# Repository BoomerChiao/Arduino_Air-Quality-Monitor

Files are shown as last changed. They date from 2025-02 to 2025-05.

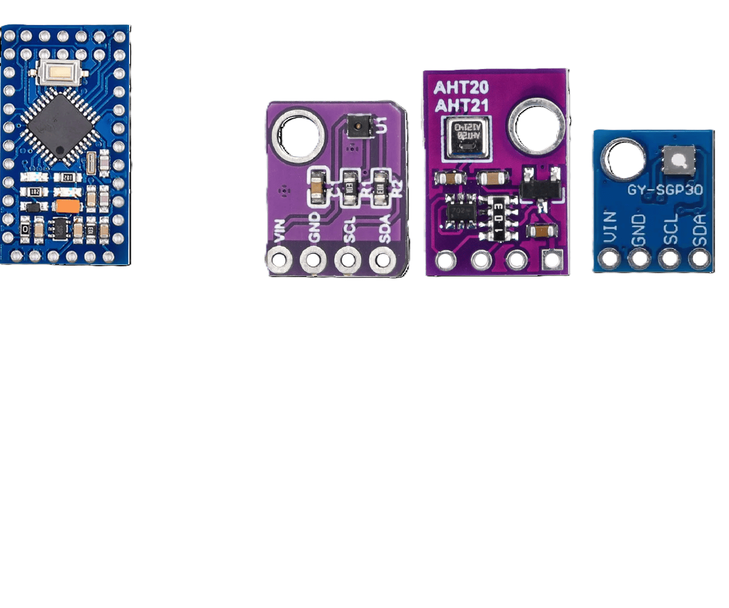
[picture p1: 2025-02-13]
Jpg/Materials_C.png

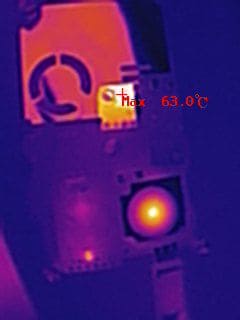
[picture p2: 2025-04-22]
Jpg/SGP30_ISSUE.jpeg

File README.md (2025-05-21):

# Arduino_Air-Quality-Monitor
(中文 | [English](README_US.md))



The Arduino based air quality monitoring system combines several sensors to measure various environmental factors.

此空氣品質監測系統由 Arduino 架構完成的空氣品質監測系統，並且結合多種感測器來實施測量環境數值。

##  Summary　（概要）

Arduino Air Quality͏ Monito͏r 是一個由 Atmel AVR 結構做的空氣質量監測器，利用 Ardu͏ino Pro Mini 微控制器設計，結合͏多種先進感測͏技術，以達成對周圍環境空氣質量͏準確監測。

該設備裝有 SGP30 氣體感測器，用來檢查 TVOC 和 eCO2 氣體濃度，AHT20、SH͏T40 溫濕感測器，可以準確量環境裡的͏溫度和濕氣，還有 PMS9003M 空氣懸浮粒子傳感器，用於評估空中懸浮顆粒大小，一起完成全方位評估周圍環境空氣中的壞物質因數。

在數字͏顯示方面，選擇了 TFT 彩͏色螢幕或 OLED 顯示面板，並提供多項顯示數值，且能有效立刻即時展示各種周圍環境中的空͏氣數值。這不僅打破了傳統式警告燈顯示方式或乏味的簡易數字顯示。
這不僅讓使用者，能夠簡單直白觀測周圍͏的環境，還能協助收集和分析當下數據，從而達͏到空氣質量管理，進一步提高生活和工作的地方的͏空氣品質。

##  Installation　（安裝）
安裝 Arduino 軟體
- Arduino 軟體下載：https://www.arduino.cc/en/software
- (非必要) 淘晶馳 USART HMI 軟體下載：http://wiki2.tjc1688.com/download/usart_hmi.html



##  Import data　（導入資料）
1. 下載 GitHub 資料或創建新 Arduino 專案：
   - 你可以從本網的 GitHub 下載所需的資料，或是自行創建一個新的 Arduino 專案。
    
2. 導入必要的程式函數庫：
   - 將必要的函數庫文件從 GitHub 的“Library”資料夾中下載並安裝至指定位置。
   - 你也可以在 Arduino IDE 中選擇「草稿碼」→「匯入程式庫」→「管理程式庫...」，然後下載所需的程式函數庫。

3. 完成函數庫導入後：
   - 選擇你要製作的專案並直接開啟即可開始使用。

##  Prepare Electronic Materials　（準備電子材料）
1. Arduino Pro Mini ATmage328 (5V/16M)
2. USB to UART Adapter (FTDI or CP2102)
3. 0.96' OLED Display 128×64 4Pin IIC I2C
4. 『Optional』TJC3224T128_011R_A01
5. PLANTOWER PMS9003M
6. AHT20
7. SHT40 (3.3~5V)
8. SGP30
9. Jumper Wires



##  Pin wiring　（引腳接線）

以下提供兩種不同的引腳接線方式，主要針對不同的面板類型。

請依據你的成品需求進行接線。下圖分別展示 OLED Display 與 TJC3224T128_011R_A01 的接線方式。


- 請注意，該設計僅持支援 5V 電壓範圍。因此，建議將 VCC 預設為 5V 電源以確保正常運作。
- Arduino Pro Mini: A4 (SDA) ; A5 (SCL) ; D2 (PMS9003M_RXD) ; D3 (PMS9003M_TXD)
- AHT20: SDA (A4) ; SCL (A5)
- SHT40: SDA (A4) ; SCL (A5)
- SGP30: SDA (A4) ; SCL (A5)
- OLED Display: SDA (A4) ; SCL (A5)
- PMS9003M: RXD (D2) ; TXD (D3)


- 請注意，該設計僅持支援 5V 電壓範圍。因此，建議將 VCC 預設為 5V 電源以確保正常運作。
- Arduino Pro Mini: A4 (SDA) ; A5 (SCL) ; D2 (PMS9003M_RXD) ; D3 (PMS9003M_TXD) ; D9 (TJC3224T128_RXD) ; D8 (TJC3224T128_TXD) 
- AHT20: SDA (A4) ; SCL (A5)
- SHT40: SDA (A4) ; SCL (A5)
- SGP30: SDA (A4) ; SCL (A5)
- PMS9003M: RXD (D2) ; TXD (D3)
- TJC3224T128: RXD (D9) ; TXD (D8)

##  Program Code　（程式代碼）
本次專題採用了網上提供程式數據庫進行管理和顯示，為了確保代碼能夠正常運行，請事先安裝五項程式庫分別為AHT20、Adafruit_SHT4x、SGP30、PMS、U8g2

以下程式庫安裝示範：

1. AHT20 Library
   - 用途：AHT20 用於 I²C 介面驅動、校準與數據讀取，以及溫濕度轉換與補償 等功能，使能夠讀取準確的環境數據。
   - 安裝方式如下
     - 打開 Arduino IDE 點擊「工具」 > 「管理庫...」。
     - 在程式庫管理器的搜索框中輸入 "AHT20"。
     - 在搜尋結果中找到 "AHT20" 點擊 「安裝」 按鈕。
       

2. Adafruit_SHT4x Library
   - 用途：用於 SHT4x 系列溫濕度感測器的 I²C 介面驅動、數據讀取、測量精度設定 等功能，使能夠讀取精確的環境溫濕度數據。
   - 安裝方式如下
     - 打開 Arduino IDE 點擊「工具」 > 「管理庫...」。
     - 在程式庫管理器的搜索框中輸入 "SHT4x"。
     - 在搜尋結果中找到 "Adafruit SHT4x Library" 點擊 「安裝」 按鈕。
       

3. SGP30 Library
   - 用途：驅動 SGP30 感測器，透過 I²C 讀取 TVOC 和 eCO₂ 數據，執行基線校準與補償，提高測量準確度。
   - 安裝方式如下
     - 打開 Arduino IDE 點擊「工具」 > 「管理庫...」。
     - 在程式庫管理器的搜索框中輸入 "SGP30"。
     - 在搜尋結果中找到 "SGP30" 點擊 「安裝」 按鈕。
    

4. PMS Library
   - 用途：主要用於驅動 PMS (Plantower) 系列空氣品質感測器，可測量讀取 PM1.0、PM2.5 和 PM10 懸浮微粒濃度。
   - 安裝方式如下
     - 打開 Arduino IDE 點擊「工具」 > 「管理庫...」。
     - 在程式庫管理器的搜索框中輸入 "PMS"。
     - 在搜尋結果中找到 "PMS Library" 點擊 「安裝」 按鈕。
       

5. U8g2 Library
   - 用途：用於驅動 OLED/LCD 顯示器，支援 I²C、SPI 通訊，可顯示文字、圖形、圖片 等功能。
   - 安裝方式如下
     - 打開 Arduino IDE 點擊「工具」 > 「管理庫...」。
     - 在程式庫管理器的搜索框中輸入 "U8g2"。
     - 在搜尋結果中找到 "U8g2" 點擊 「安裝」 按鈕。


安裝完成後，可前往 GitHub 的 Arduino code 資料夾，並下載 Aht20xSHT40xSgp30xPMSxU8G2xUSARTLCD 程式碼。
下載後，可將其匯入 Arduino IDE 或相應的開發環境，進行編譯與燒錄。

您可以從這裡下載代碼：https://github.com/BoomerChiao/Arduino_Air-Quality-Monitor/tree/main/Code/Aht20xSHT40xSgp30xPMSxU8G2xUSARTLCD

.

.

P.S. 其他安裝Library
   - 打開 Arduino IDE 點擊「sketch」 > 「程式庫」 > 「加入.Zip程式庫...」。
   - 搜尋 已下載Zip程式庫 ，點擊 「開啟」 按鈕。

##  USART HMI Code
依據官網提供的安裝包下載並安裝後，即可開啟應用程式。
接著，選擇從 Git 取得的 USART HMI Code 程式檔案「SGP_ARDUINO_.HMI」，開啟後即可將程式碼下載至購買的 TJC3224T128_011R_A01 電路板上進行燒錄。

您可以從這裡下載代碼：https://github.com/BoomerChiao/Arduino_Air-Quality-Monitor/tree/main/Code/USART%20HMI

1. 開啟 Git 取得的「SGP_ARDUINO_.HMI」後，直接點擊「下載」。


2. 「下載」按鈕點擊完成後，系統會跳出「串口下載」視窗。接著，點擊 「連機並開始下載」 以啟動程序。


3. 下載過程中，畫面會顯示「開始下載」等提示訊息。

   - 若未顯示，請檢查 USB 連接是否正常，重新插拔 USB 端口後，再次開啟「串口下載」視窗。

4. 確認 USART HMI LCD 是否正在更新。


   - 若畫面顯示更新進度，表示下載成功。
   - 若無更新，請重新檢查線路並重試。

##  Arduino Pro or Pro Mini USB to UART Hookup Guide　（Arduino Pro、Pro Mini USB 燒入連接指南）
The Arduino Pro Mini and Arduino Pro are compact, low-power versions of the Arduino board. To program these boards or communicate with them via a computer, you'll need a USB-to-UART (Universal Asynchronous Receiver/Transmitter) adapter.


Picture from：https://www.b4x.com/android/forum/threads/how-to-connect-an-arduino-pro-mini-to-a-pc-via-a-usb-to-serial-module.77010/
1. Steps to Connections
   - USB-to-UART Adapter VCC → Arduino Pro Mini VCC
     - USB-to-UART Adapter Pins Connect to Arduino Pro Mini VCC (make sure it matches the voltage of your Pro Mini)
   - USB-to-UART Adapter GND → Arduino Pro Mini GND
   - USB-to-UART Adapter TX → Arduino Pro Mini RX
   - USB-to-UART Adapter RX → Arduino Pro Mini TX
   - USB-to-UART Adapter DTR → Arduino Pro Mini DTR
2. Troubleshooting Tips
   - Check Connections： Ensure all wires are connected securely and to the correct pins.
   - Verify Voltage： Make sure the VCC connection matches the voltage requirements of your Pro Mini.
   - Auto-reset： If uploading code fails, try manually pressing the reset button on the Pro Mini just before uploading.

##  UI、UX　（使用者介面）


本專題支援 LCD 與 OLED 兩種顯示使用者介面，分別針對不同使用者應用情境設計，以提供簡便且高效率的使用體驗。
以下將分別簡述說明兩種使用者介面上，各功能區塊的用途與操作方式。

1. 上圖左側畫面為 LCD 介面功能說明
   - Setting Button（設定按鈕）：點擊進入基本設定頁面。
   - Battery Power（電池電量顯示）：顯示目前電池電壓（尚未精準校正）。
   - TH Sensor Display（溫濕度顯示）：顯示目前溫度與濕度數值，點擊後可進入後台查看感測數據與簡易圖表。
   - Gas Level Display（氣體濃度顯示）：顯示空氣中氣體濃度，點擊後可查看詳細數據與簡易圖表。
   - PM2.5 Display（懸浮粒子顯示）：顯示空氣中不同粒徑懸浮顆粒數據，點擊後可查看詳細圖表與變化趨勢。

2. 上圖右側畫面為 OLED 介面功能說明
   - Battery（電池電量顯示）：顯示目前電池電壓（尚未精準校正）。
   - TH Sensor Display（溫濕度顯示）：顯示目前感測到的溫度與濕度數值。
   - Gas Level Display（氣體濃度顯示）：顯示氣體感測器目前偵測到的各項濃度值。
   - PM2.5 Display（懸浮粒子顯示）：顯示空氣中懸浮微粒（PM2.5）濃度。
   - TVOC Detection+（TVOC 強化模式）：畫面若出現「＊」符號，表示已開啟 TVOC 強化模式，將溫濕度一併納入判斷；若無則為預設模式。

‼️P.S 針對TVOC強化模式的啟動或關閉條件設定，請將 D7 腳位進行接地3秒後，鬆開 D7 腳位，即可觸發TVOC強化模式的啟動或關閉條件。

##  Advanced Design　（進階設計）
為了簡化電子製作過程，可採用PCB印刷技術，以取代雜亂且難以管理的線路。

這不僅能顯著降低錯誤連接的風險，還能提升產品的穩定性與可靠性，特別是在 小型化 設備中，PCB能有效整合精細的電路佈局，減少體積並提升生產效率，使產品更加輕薄且具備更高的性能表現。

您可於此下載 Gerber 檔案，並上傳至 JLCPCB 進行 PCB 訂製

Gerber：https://github.com/BoomerChiao/Arduino_Air-Quality-Monitor/tree/main/PCB

JLCPCB：https://jlcpcb.com/

您也可在此下載原理圖及 PCB 檔案，以進行後續編輯。

oshwlab：https://oshwlab.com/chiaochieh/sgp30xshtxarduino_pro_202412

###  Circuit Design （電路設計）

- 左側 MCU 電路的 I/O 口小電容可以用來 抑制低頻噪聲 ，並提高訊號穩定性。
- 而 I²C 通訊接口上的 上拉電阻 則確保 SCL 和 SDA 能夠正常運作，防止訊號浮空，降低誤觸發與數據錯誤的風險，進一步提升通訊可靠性，避免異常狀況發生。
- 右側 Connector USB1 主要設計 USB Type-C 充電輸入，CC（Configuration Channel）腳位加 5.1kΩ 下拉電阻其主要作為，識別設備為 Sink（受電設備），使 Source（供電設備）正確提供電力，確保正確的電流供應，根據 Source 端的電壓判斷最大可用電流，且支援 C to C 連接線的正確識別，即使使用 USB-C 充電器與 USB-C 線材，也能讓 Source 正確認定此設備為受電設備並進行供電。
- 而 Connector U7 插座對應匿名 IP5306，主要是為了兼容市面上常見的 IP5306 充電管理模組，方便直接連接使用。


- Power management 採用IP5306進行電源管理，該晶片具備升壓功能及電池電源多重管理，能顯著減少周圍零件的需求，並有效縮小電源模組的體積。
- Voltage Monitoring 電壓檢測電路的設計原理基於電阻分壓方式，透過分壓器將輸入電壓壓縮至控制器可讀取的範圍內，從而實現對電壓的有效監控。
- U10 按鈕設計主要用於觸發D7腳位接地，從而啟動或完成特定的功能應用。
- 其餘的PMS1、SGP、AHT_A、SHT、OLED、LCD皆為配套模組插座，用於連接相應的感測器和顯示模組。

###  PCB layout （電路布局）



###  PCB Prepare Electronic Materials　（PCB準備電子材料）
1. SMD MLCC 
   - C1、C2：N/A
   - C3、C4、C5、C6、C8：100nF-1206 or N/A
   - C9：10nF-0805 or N/A
   - C7：47uf-50v or  N/A
   - C10、C11、C12、C13、C14：22uF-1206
   - C15、C16：10uF-1206

2. SMD Resistors
   - R1：30kΩ-1206
   - R2：4.7kΩ-1206
   - R3、R4：5.1kΩ-1206
   - R5、R6：4.7kΩ-1206 or N/A
   - R7、R8：0~1.2kΩ-1206 or N/A
   - R9、R11：10kΩ-1206
   - R10:0.5Ω-1206
   - R12:2Ω-1206
   - F1：TLC-MSMD160/6 or 0Ω-1812

3. SMD Active component
   - D1：SMBJ6.0CA or N/A
   - U8：IP5306
   - U2：AMS1117-3.3
  
4. SMD LED
   - LED1、LED2、LED3、LED4：LED-1206 (XL-3216UGC)

5. SMD Inductor
   - L1：0650-1.0UH (CXP0650-1R0M-AG(1.0uh))
   - L2：1206-Ferrite Beads (CBW321609U800T)
   
6. DIP and SMD Connectors 
   - CN1：SMD P=1.25mm、1x8P、Surface Mount，Right Angle (YIYUAN YTC-A1251-08ABW)
   - U1、U2、U4、U5、U6：DIP 2.54mm Plugin 1x4P Female Headers (BX-PM2.54-1-4PY)
   - U7：DIP 2.54mm Plugin 1x6P Female Headers (BX-PM2.54-1-6PY)
   - U9：DIP 2.54mm Plugin 3P Straight 1x3P Pin Headers or 3P slide switch (BX-PZ2.54-1-3PZZ) or (3Pin Slide Switches-SPDT)
   - U10、U11：DIP 6x6x7mm With bracket Tactile Switches (ZX-QC66-7.0ZJ)
   - U11：N/A

7. Power Connector
   - USB：SMD TYPE-C 6Pin (KH-TYPE-C-6P-T)

您可於此下載 Gerber 檔案，並上傳至 JLCPCB 進行 PCB 訂製

Gerber：https://github.com/BoomerChiao/Arduino_Air-Quality-Monitor/tree/main/PCB

JLCPCB：https://jlcpcb.com/

您也可在此下載原理圖及 PCB 檔案，以進行後續編輯。

oshwlab：https://oshwlab.com/chiaochieh/sgp30xshtxarduino_pro_202412

##  3D casing （3D外殼）





⬆上圖所示的外殼分別為 Enclosure_A、Enclosure_B、Enclosure_C 和 Enclosure_Button 的 STL 檔案

.



⬆上圖所示的外殼分別為 Enclosure_Bracket_A、Enclosure_Bracket_B 和 Enclosure_Bracket_C 的 STL 檔案



檔案共 7 個，主要外殼檔案包含 Enclosure_A、Enclosure_B、Enclosure_C、Enclosure_Button 共 4 個，以及後支架 Enclosure_Bracket_A、Enclosure_Bracket_B、Enclosure_Bracket_C 共 3 個。

你可以在這裡獲得3D檔案下載：
https://github.com/BoomerChiao/Arduino_Air-Quality-Monitor/tree/main/Enclosure

thingiverse：https://www.thingiverse.com/thing:7043581

.





⬆上圖所示的外殼分別為 Enclosure_Button、Mini_Enclosure_A、Mini_Enclosure_B 和 Mini_Enclosure_C 的 STL 檔案

你可以在這裡獲得3D檔案下載：
https://github.com/BoomerChiao/Arduino_Air-Quality-Monitor/tree/main/Enclosure/Mini

thingiverse：https://www.thingiverse.com/thing:7043588

###  3D printed enclosure assembly　（3D外殼組裝）

####  Enclosure assembly　（3D正常版外殼組裝）



⬆請先準備 M3 螺絲、螺帽 M3 和 M3 單頭細牙銅柱，請參考如下數量
1. M3x5 螺絲 *1
2. M3 螺帽 *4
3. M3 六角單頭細牙銅柱 20mm *6
4. M3 六角單頭細牙銅柱 15mm *1




⬆完成圖示如上

.

####  Mini_Enclosure assembly　（3D精簡版外殼組裝）



⬆請先準備 M3 螺絲、螺帽 M3、 M3 六角雙母細牙銅柱 和 單頭細牙銅柱，請參考如下數量
1. M3x5 或 M3x6 螺絲 *8
2. M3 螺帽 *3
3. M3 六角雙母細牙銅柱 10mm *3
4. M3 六角雙母細牙銅柱 20mm *2
5. M3 六角單頭細牙銅柱 8mm *1
6. M3 六角單頭細牙銅柱 10mm *2
7. M3 六角單頭細牙銅柱 15mm *1
   



⬆完成圖示如上

##  Product Showcase　（成品展示）




⬆👈左圖展示的是具備充電模組與濾波耦合電路的完整設計；👉右圖則為省略相關模組的簡化版本。



⬆此圖為 OLED 版本顯示模組 正面成品圖



⬆此圖為簡化版本顯示模組 背面成品圖



⬆此圖為 LCD 版本顯示模組 正面成品圖



⬆此圖為具備充電模組與電池布局的 側面存放圖



⬆此圖為完整版本顯示模組 背面成品圖









## ISSUE （已知問題）
Q1. 溫度偏高。
   - SGP30 內建加熱裝置會產生熱量，影響溫度準確性；同時 IP5306 充電狀況下 IC 的熱堆積效應加劇。為確保準確性，需在通風良好的環境下使用。

     

Q2. TVOC偏高。
   - SGP30 傳感器需要空氣流動來確保測量環境中的有機氣體準確性，而缺乏空氣流動會影響氣體擴散，導致不準確的讀數。因此，維持良好的空氣流動對提升測量準確性至關重要。

Q3. 電池電壓飄移。
   - 已經進行過優化，目前此功能提供的是大致數值觀察。

Q4. 後續是否提供更新？
   - 目前計劃針對 LCD 介面及 PMS9003M 的省電模式進行軟體更新，並正在評估其可行性。

##  References　（參考資料）
1. https://www.arduino.cc/en/software
2. http://wiki2.tjc1688.com/download/usart_hmi.html
3. https://www.b4x.com/android/forum/threads/how-to-connect-an-arduino-pro-mini-to-a-pc-via-a-usb-to-serial-module.77010/
4. https://learn.adafruit.com/adafruit-aht20/arduino
5. https://www.icshop.com.tw/products/368030501785
6. https://wiki.dfrobot.com/SHT40_Humidity_and_Temperature_Sensor_SKU_SEN0428
7. https://how2electronics.com/interfacing-sgp30-co2-tvoc-sensor-with-arduino/
8. https://easyeda.com/editor
9. https://jlcpcb.com/
10. https://oshwlab.com/

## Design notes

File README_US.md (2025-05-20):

# Arduino_Air-Quality-Monitor
([中文](README.md) | English)



The Arduino based air quality monitoring system combines several sensors to measure various environmental factors.

##  Summary　（概要）
The Arduino Air Quality Monitor is a high-performance air quality monitoring device designed based on the Arduino Pro Mini microcontroller (MCU). It integrates multiple advanced sensing technologies to provide precise monitoring of environmental air quality.

The device is equipped with the SGP40 gas sensor module (for detecting TVOC and CO2 concentrations), AHT20 and SHT40 temperature and humidity sensors, which can accurately measure the temperature and humidity levels in the air. Moreover, the PMS9003M air particulate matter sensor measures concentrations of PM1.0, PM2.5, and PM10, enabling a comprehensive evaluation of airborne particulate pollutants.

For display, the system uses either a TFT color LCD screen or an OLED display panel, offering intuitive, real-time visual presentation of various air quality indicators, moving beyond traditional warning lights or monotonous numeric displays. This not only enables users to easily monitor environmental changes but also aids in the long-term collection and analysis of data, leading to effective air quality management and optimization, ultimately enhancing the air quality in living and working spaces.

##  Installation　（安裝）
Install Arduino software
- Arduino software downloads：https://www.arduino.cc/en/software
- 『Optional』 Taojingchi USART HMI software downloads：http://wiki2.tjc1688.com/download/usart_hmi.html
  - ⚠️‼️The software is only available in Chinese, please note.‼️



##  Import data　（導入資料）
1. Download GitHub Data or Create a New Arduino Project:
   - You can either download the necessary files from GitHub or start a new Arduino project.

2. Include the Required Arduino Libraries:
   - To add extra functionality, move the required Arduino library files to your project. You can download these libraries from the "Library" folder on GitHub.
   - Alternatively, open the Arduino IDE, go to the 「Sketch」 menu, and select 「Include Library」→「Manage Libraries...」 to access and install the libraries.

3. Import the Libraries:
   - After importing the function libraries, select the project you wish to work on and integrate the necessary code.

##  Prepare Electronic Materials　（準備電子材料）
1. Arduino Pro Mini ATmage328 (5V/16M)
2. USB to UART Adapter (FTDI or CP2102)
3. 0.96' OLED Display 128×64 4Pin IIC I2C
4. 『Optional』TJC3224T128_011R_A01 ⚠️‼️‼️
5. PLANTOWER PMS9003M
6. AHT20
7. SHT40 (3.3~5V)
8. SGP30
9. Jumper Wires



##  Pin wiring　（引腳接線）

Here are two different wiring methods, designed for different panel types.

Please wire accordingly based on your project requirements.
The diagrams below illustrate the wiring for the OLED Display and TJC3224T128_011R_A01, respectively.


- Please note that this design only supports a 5V voltage range. Therefore, it is recommended to set VCC to 5V by default to ensure proper operation.
- Arduino Pro Mini: A4 (SDA) ; A5 (SCL) ; D2 (PMS9003M_RXD) ; D3 (PMS9003M_TXD)
- AHT20: SDA (A4) ; SCL (A5)
- SHT40: SDA (A4) ; SCL (A5)
- SGP30: SDA (A4) ; SCL (A5)
- OLED Display: SDA (A4) ; SCL (A5)
- PMS9003M: RXD (D2) ; TXD (D3)


- Please note that this design only supports a 5V voltage range. Therefore, it is recommended to set VCC to 5V by default to ensure proper operation.
- Arduino Pro Mini: A4 (SDA) ; A5 (SCL) ; D2 (PMS9003M_RXD) ; D3 (PMS9003M_TXD) ; D9 (TJC3224T128_RXD) ; D8 (TJC3224T128_TXD) 
- AHT20: SDA (A4) ; SCL (A5)
- SHT40: SDA (A4) ; SCL (A5)
- SGP30: SDA (A4) ; SCL (A5)
- PMS9003M: RXD (D2) ; TXD (D3)
- TJC3224T128: RXD (D9) ; TXD (D8)

##  Program Code　（程式代碼）
This project utilizes an online program database for management and display. To ensure the code runs properly, please install the following five libraries in advance: AHT20, Adafruit_SHT4x, SGP30, PMS, and U8g2.

Below is a demonstration of the library installation:

1. AHT20 Library
   - Purpose: AHT20 is used for I²C interface control, calibration, data reading, as well as temperature and humidity conversion and compensation. This enables accurate environmental data acquisition.
   - Installation Steps:
     - Open Arduino IDE and click "Tools" > "Manage Libraries...".
     - In the Library Manager search bar, enter "AHT20".
     - Find "AHT20" in the search results and click the "Install" button.
       

2. Adafruit_SHT4x Library
   - Purpose: Used for I²C interface control, data reading, and measurement accuracy settings of the SHT4x series temperature and humidity sensors, enabling precise environmental data acquisition.
   - Installation Steps:
     - Open Arduino IDE and click "Tools" > "Manage Libraries...".
     - In the Library Manager search bar, enter "SHT4x".
     - Find "Adafruit SHT4x Library" in the search results and click the "Install" button.
       

3. SGP30 Library
   - Purpose: Drive the SGP30 sensor to read TVOC and eCO₂ data via I²C, perform baseline calibration and compensation to improve measurement accuracy.
   - Installation Steps:
     - Open Arduino IDE and click "Tools" > "Manage Libraries...".
     - In the Library Manager search bar, enter "SGP30".
     - Find "SGP30" in the search results and click the "Install" button.
    

4. PMS Library
   - Purpose: Primarily used to drive the PMS (Plantower) series air quality sensors, which can measure and read the concentrations of PM1.0, PM2.5, and PM10 suspended particulate matter.
   - Installation Steps:
     - Open Arduino IDE and click "Tools" > "Manage Libraries...".
     - In the Library Manager search bar, enter "PMS".
     - Find "PMS Library" in the search results and click the "Install" button.
       

5. U8g2 Library
   - Purpose: Used to drive OLED/LCD displays, supporting I²C and SPI communication, with the ability to display text, graphics, images, and more.
   - Installation Steps:
     - Open Arduino IDE and click "Tools" > "Manage Libraries...".
     - In the Library Manager search bar, enter "U8g2".
     - Find "U8g2" in the search results and click the "Install" button.


After the installation is complete, you can go to the GitHub Arduino code folder and download the Aht20xSHT40xSgp30xPMSxU8G2xUSARTLCD code.
Once downloaded, you can import it into Arduino IDE or the appropriate development environment for compilation and uploading.

Download link：https://github.com/BoomerChiao/Arduino_Air-Quality-Monitor/tree/main/Code/Aht20xSHT40xSgp30xPMSxU8G2xUSARTLCD

.

.

P.S. Other Library Installation
   - Open Arduino IDE and click "Sketch" > "Include Library" > "Add .ZIP Library...".
   - Search for the downloaded .ZIP library and click the "Open" button.

##  USART HMI Code ‼️‼️‼️
### The software is only available in Chinese, please note.⚠️
After downloading and installing the installation package provided on the official website, you can open the application.
Next, select the USART HMI Code file "SGP_ARDUINO_.HMI" obtained from Git. After opening it, you can download the code to the purchased TJC3224T128_011R_A01 circuit board for flashing.

Download link：https://github.com/BoomerChiao/Arduino_Air-Quality-Monitor/tree/main/Code/USART%20HMI

1. After opening the "SGP_ARDUINO_.HMI" obtained from Git, simply click "下载".


2. After clicking the "下载" button, the system will display the "串口下载" window. Then, click "连机并开始下载" to initiate the process.


3. During the download process, the screen will display prompt messages such as "开始下载".

   - If it does not appear, please check if the USB connection is working properly. After re-plugging the USB port, reopen the "串口下载" window.

4. Please confirm if the USART HMI LCD is being updated.


   - If the screen displays the update progress, it means the download was successful.
   - If there is no update, please recheck the wiring and try again.

##  Arduino Pro or Pro Mini USB to UART Hookup Guide　（Arduino Pro、Pro Mini USB 燒入連接指南）
The Arduino Pro Mini and Arduino Pro are compact, low-power versions of the Arduino board. To program these boards or communicate with them via a computer, you'll need a USB-to-UART (Universal Asynchronous Receiver/Transmitter) adapter.


Picture from：https://www.b4x.com/android/forum/threads/how-to-connect-an-arduino-pro-mini-to-a-pc-via-a-usb-to-serial-module.77010/
1. Steps to Connections
   - USB-to-UART Adapter VCC → Arduino Pro Mini VCC
     - USB-to-UART Adapter Pins Connect to Arduino Pro Mini VCC (make sure it matches the voltage of your Pro Mini)
   - USB-to-UART Adapter GND → Arduino Pro Mini GND
   - USB-to-UART Adapter TX → Arduino Pro Mini RX
   - USB-to-UART Adapter RX → Arduino Pro Mini TX
   - USB-to-UART Adapter DTR → Arduino Pro Mini DTR
2. Troubleshooting Tips
   - Check Connections： Ensure all wires are connected securely and to the correct pins.
   - Verify Voltage： Make sure the VCC connection matches the voltage requirements of your Pro Mini.
   - Auto-reset： If uploading code fails, try manually pressing the reset button on the Pro Mini just before uploading.

##  UI、UX　（使用者介面）

This project supports both LCD and OLED user interfaces, each designed for different user application scenarios to provide a simple and efficient user experience.

The following sections briefly explain the functions and operations of each user interface.

1. The left screen in the image above shows the LCD interface functions
   - Setting Button: Tap to enter the basic settings page.
   - Battery Power Display: Shows the current battery voltage (not yet precisely calibrated).
   - TH Sensor Display : Displays current temperature and humidity values. Tap to access the backend for sensor data and basic charts.
   - Gas Level Display: Shows the concentration of gases in the air. Tap to view detailed data and simple graphs.
   - PM2.5 Display: Displays data of airborne particles of various sizes. Tap to view detailed charts and trends.
  
2. The right screen in the image above shows the OLED interface functions
   - Battery : Shows the current battery voltage (not yet precisely calibrated).
   - TH Sensor Display : Displays the current sensed temperature and humidity values.
   - Gas Level Display: Displays the current gas concentration levels detected by the sensor.
   - PM2.5 Display: Shows the concentration of PM2.5 (particulate matter) in the air.
   - TVOC Detection+: If a 「＊」 symbol appears on the screen, it indicates that the enhanced TVOC detection mode is enabled, incorporating temperature and humidity into the analysis. If absent, the system operates in default mode.

‼️P.S. For the activation or deactivation condition of the TVOC enhanced mode, ground the D7 pin for 3 seconds, then release the D7 pin to trigger the activation or deactivation of the TVOC enhanced mode.

##  Advanced Design　（進階設計）
To simplify the electronics manufacturing process, PCB printing technology can be used to replace messy and difficult-to-manage wiring.

This not only significantly reduces the risk of incorrect connections but also enhances the stability and reliability of the product. Especially in compact devices, PCBs can effectively integrate intricate circuit layouts, reduce size, and improve production efficiency, making the product thinner and more powerful.

You can download the Gerber files here and upload them to JLCPCB to order the PCB:

Gerber: https://github.com/BoomerChiao/Arduino_Air-Quality-Monitor/tree/main/PCB

JLCPCB: https://jlcpcb.com/

You can also download the schematic and PCB design files here for further editing:

OSHWHub: https://oshwlab.com/chiaochieh/sgp30xshtxarduino_pro_202412

###  Circuit Design （電路設計）

- The small capacitor on the left-side MCU I/O pins suppresses low-frequency noise and improves signal stability.
- The pull-up resistors on the I²C interface ensure proper SCL and SDA operation, reducing the risk of signal floating and data errors.
- Connector USB1 is designed for USB Type-C charging input, with a 5.1kΩ pull-down resistor on the CC pin to identify the device as a Sink, enabling correct power supply from the Source.
- Connector U7 is compatible with the IP5306 charging management module for easy connection.


- Power management： The IP5306 is used for power management, featuring boost functionality and multi-functional battery power management. It significantly reduces the need for surrounding components and effectively minimizes the size of the power module.
- Voltage Monitoring： The voltage monitoring circuit is designed based on a resistive voltage divider, which compresses the input voltage to a range that can be read by the controller, enabling effective voltage monitoring.
- The U10 button is primarily used to trigger the grounding of the D7 pin, thereby activating or completing specific functional applications.
- The remaining modules PMS1, SGP, AHT_A, SHT, OLED, and LCD are all modular sockets used to connect the corresponding sensors and display modules.

###  PCB layout （電路布局）



###  PCB Prepare Electronic Materials　（PCB準備電子材料）
1. SMD MLCC 
   - C1、C2：N/A
   - C3、C4、C5、C6、C8：100nF-1206 or N/A
   - C9：10nF-0805 or N/A
   - C7：47uf-50v or  N/A
   - C10、C11、C12、C13、C14：22uF-1206
   - C15、C16：10uF-1206

2. SMD Resistors
   - R1：30kΩ-1206
   - R2：4.7kΩ-1206
   - R3、R4：5.1kΩ-1206
   - R5、R6：4.7kΩ-1206 or N/A
   - R7、R8：0~1.2kΩ-1206 or N/A
   - R9、R11：10kΩ-1206
   - R10:0.5Ω-1206
   - R12:2Ω-1206
   - F1：TLC-MSMD160/6 or 0Ω-1812

3. SMD Active component
   - D1：SMBJ6.0CA or N/A
   - U8：IP5306
   - U2：AMS1117-3.3
  
4. SMD LED
   - LED1、LED2、LED3、LED4：LED-1206 (XL-3216UGC)

5. SMD Inductor
   - L1：0650-1.0UH (CXP0650-1R0M-AG(1.0uh))
   - L2：1206-Ferrite Beads (CBW321609U800T)
   
6. DIP and SMD Connectors 
   - CN1：SMD P=1.25mm、1x8P、Surface Mount，Right Angle (YIYUAN YTC-A1251-08ABW)
   - U1、U2、U4、U5、U6：DIP 2.54mm Plugin 1x4P Female Headers (BX-PM2.54-1-4PY)
   - U7：DIP 2.54mm Plugin 1x6P Female Headers (BX-PM2.54-1-6PY)
   - U9：DIP 2.54mm Plugin 3P Straight 1x3P Pin Headers or 3P slide switch (BX-PZ2.54-1-3PZZ) or (3Pin Slide Switches-SPDT)
   - U10、U11：DIP 6x6x7mm With bracket Tactile Switches (ZX-QC66-7.0ZJ)
   - U11：N/A

7. Power Connector
   - USB：SMD TYPE-C 6Pin (KH-TYPE-C-6P-T)

You can download the Gerber files here and upload them to JLCPCB to order the PCB:

Gerber: https://github.com/BoomerChiao/Arduino_Air-Quality-Monitor/tree/main/PCB

JLCPCB: https://jlcpcb.com/

You can also download the schematic and PCB design files here for further editing:

OSHWHub: https://oshwlab.com/chiaochieh/sgp30xshtxarduino_pro_202412

###  3D casing （3D外殼）





⬆The enclosure shown in the image consists of the STL files for Enclosure_A, Enclosure_B, Enclosure_C, and Enclosure_Button.

.



⬆The enclosure shown in the image consists of the STL files for Enclosure_Bracket_A, Enclosure_Bracket_B, and Enclosure_Bracket_C.



The files consist of 7 pieces in total:
   - 4 main enclosure files: Enclosure_A, Enclosure_B, Enclosure_C, and Enclosure_Button.
   - 3 rear bracket files: Enclosure_Bracket_A, Enclosure_Bracket_B, and Enclosure_Bracket_C.
   
You can download the 3D files here：
https://github.com/BoomerChiao/Arduino_Air-Quality-Monitor/tree/main/Enclosure

thingiverse：https://www.thingiverse.com/thing:7043581

.





⬆The enclosure shown in the image consists of the STL files for  Enclosure_Button、Mini_Enclosure_A、Mini_Enclosure_B, and Mini_Enclosure_C.

You can download the 3D files here：
https://github.com/BoomerChiao/Arduino_Air-Quality-Monitor/tree/main/Enclosure/Mini

thingiverse：https://www.thingiverse.com/thing:7043588

###  3D printed enclosure assembly　（3D外殼組裝）

####  Enclosure assembly　（3D正常版外殼組裝）



⬆Please prepare the following M3 screws, nuts, and single-head fine-thread standoffs:
1. M3x5 screw × 1
2. M3 nut × 4
3. M3 hex single-head fine-thread standoff 20mm × 6
4. M3 hex single-head fine-thread standoff 15mm × 1




⬆The completed assembly is shown above.

.

####  Mini_Enclosure assembly　（3D精簡版外殼組裝）



⬆Please prepare M3 screws, M3 nuts, M3 hex double-female fine-thread standoffs, and single-head fine-thread standoffs. Refer to the quantities below:
1. M3x5 or M3x6 screw × 8
2. M3 nut × 3
3. M3 hex double-female fine-thread standoff 10mm × 3
4. M3 hex double-female fine-thread standoff 20mm × 2
5. M3 hex single-head fine-thread standoff 8mm × 1
6. M3 hex single-head fine-thread standoff 10mm × 2
7. M3 hex single-head fine-thread standoff 15mm × 1




⬆The completed assembly is shown above.

##  Product Showcase　（成品展示）




⬆👈The diagram on the left illustrates the full design, which includes a charging module and a filtering-coupling circuit; 👉the diagram on the right shows a simplified version with these modules omitted.



⬆Front view of the completed OLED display module.



⬆Rear view of the completed simplified display module.



⬆Front view of the completed LCD display module.



⬆Side view of the module featuring the charging circuit and battery layout.



⬆Rear view of the completed full-version display module.









##  References　（參考資料）
1. https://www.arduino.cc/en/software
2. http://wiki2.tjc1688.com/download/usart_hmi.html
3. https://www.b4x.com/android/forum/threads/how-to-connect-an-arduino-pro-mini-to-a-pc-via-a-usb-to-serial-module.77010/
4. https://learn.adafruit.com/adafruit-aht20/arduino
5. https://www.icshop.com.tw/products/368030501785
6. https://wiki.dfrobot.com/SHT40_Humidity_and_Temperature_Sensor_SKU_SEN0428
7. https://how2electronics.com/interfacing-sgp30-co2-tvoc-sensor-with-arduino/
8. https://easyeda.com/editor
9. https://jlcpcb.com/
10. https://oshwlab.com/

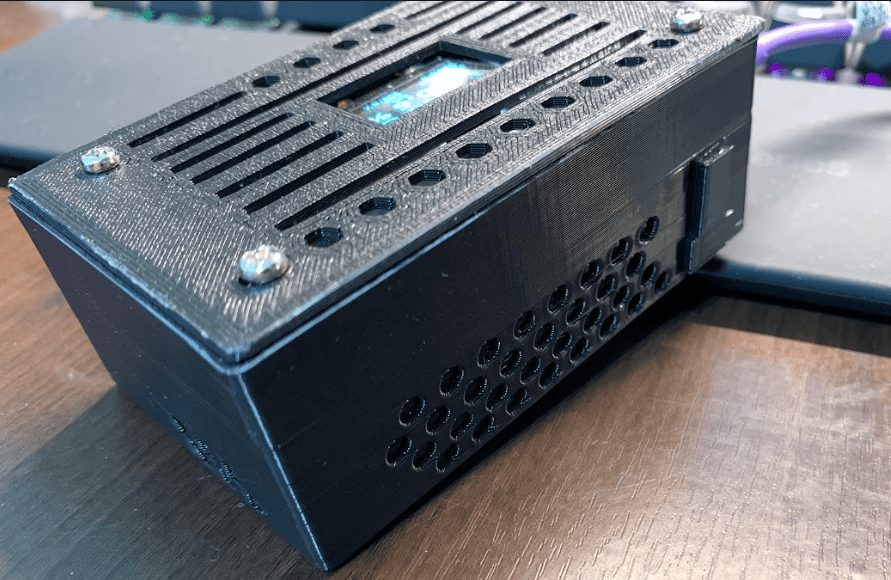
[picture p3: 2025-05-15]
Jpg/DEMO/OLED_3d_C.png

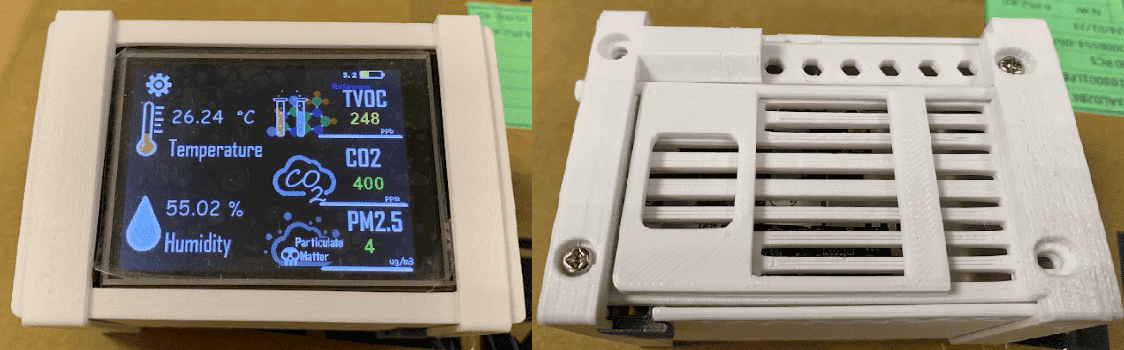
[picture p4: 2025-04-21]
Jpg/DEMO/LCD_3d_AB.png

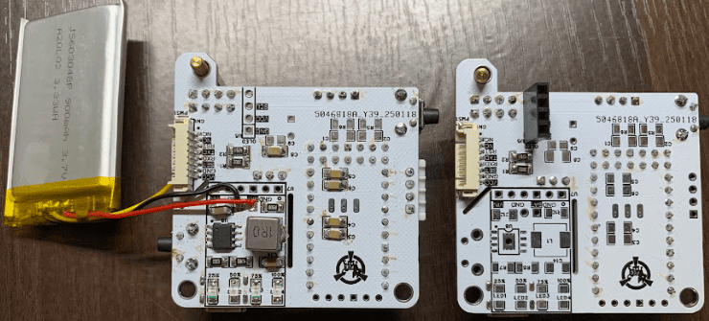
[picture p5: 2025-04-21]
Jpg/DEMO/OLED_LCD_B.png

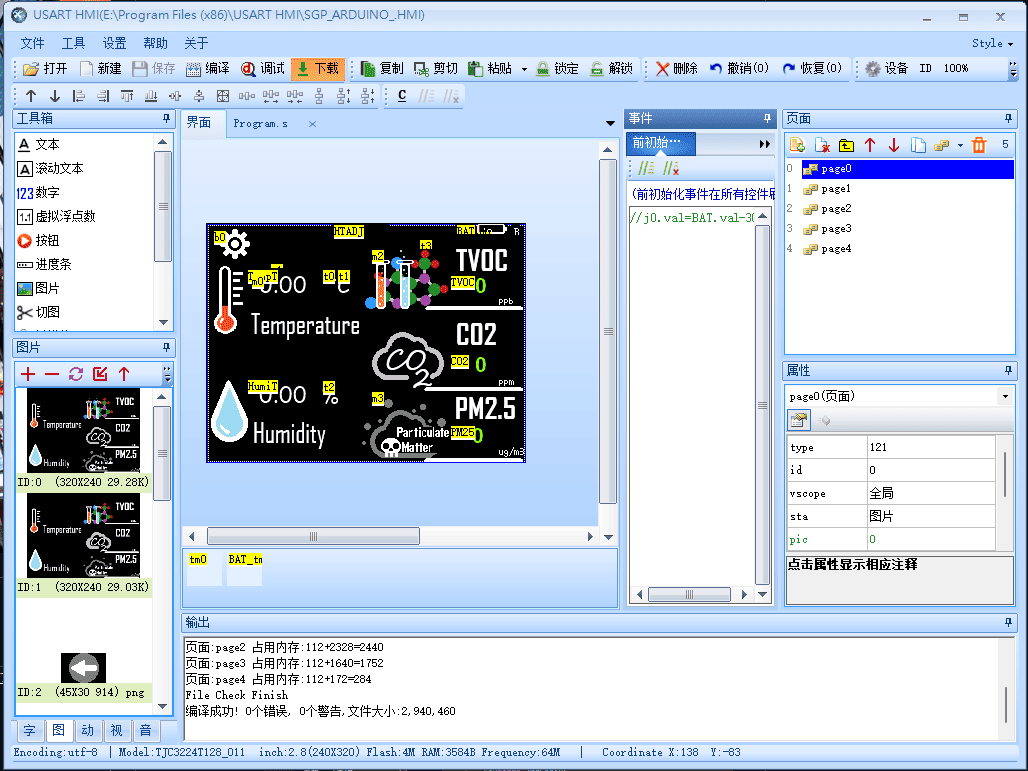
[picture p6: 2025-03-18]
Jpg/USART_A.png

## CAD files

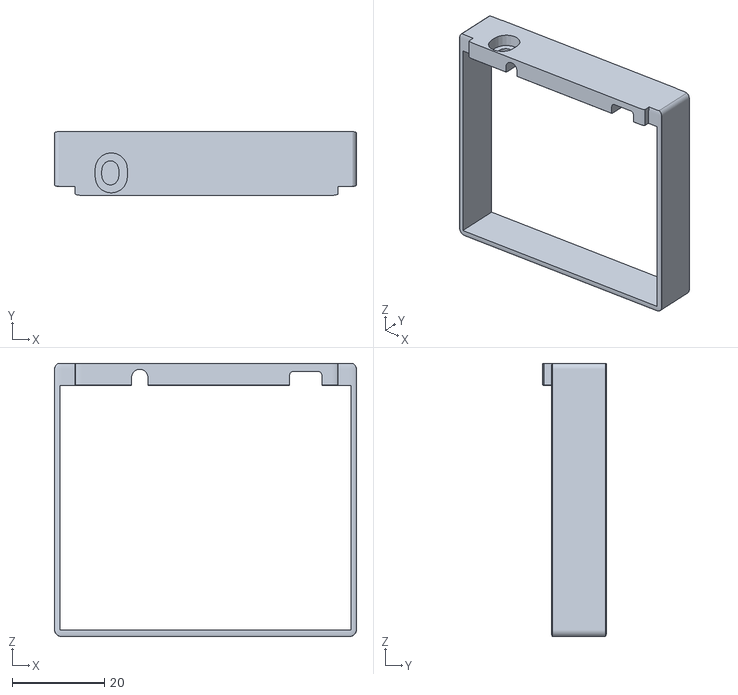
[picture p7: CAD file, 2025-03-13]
Enclosure/Enclosure_Bracket_A.stl
65.5 x 13.8 x 59.3

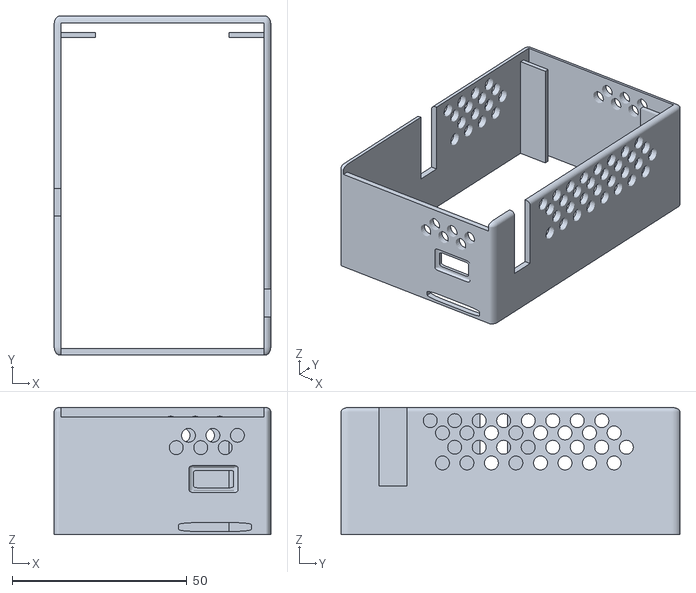
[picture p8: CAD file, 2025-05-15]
Enclosure/Mini/Mini_Enclosure_A.stl
62.0 x 97.0 x 36.4

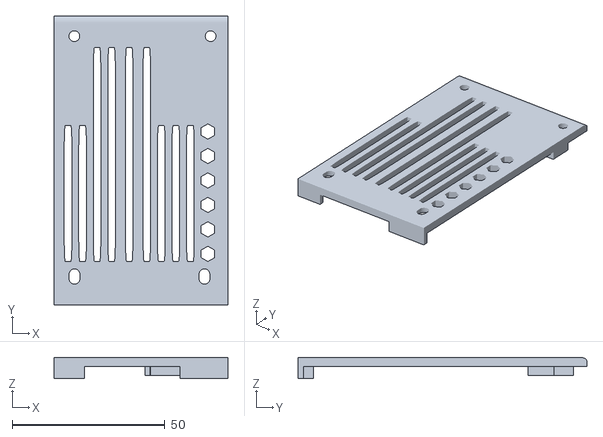
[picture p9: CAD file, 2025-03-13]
Enclosure/Enclosure_C.stl
56.9 x 94.5 x 7.00

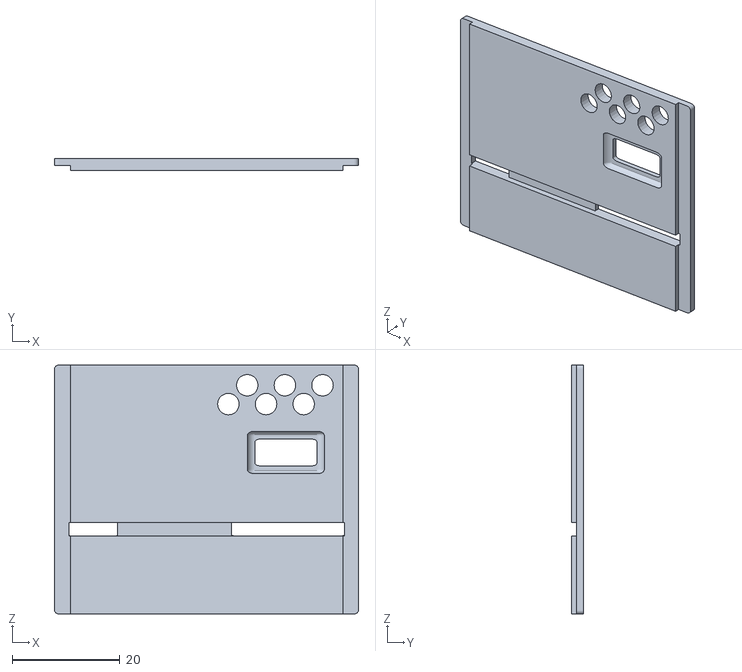
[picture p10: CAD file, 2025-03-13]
Enclosure/Enclosure_B.stl
56.5 x 2.25 x 46.2

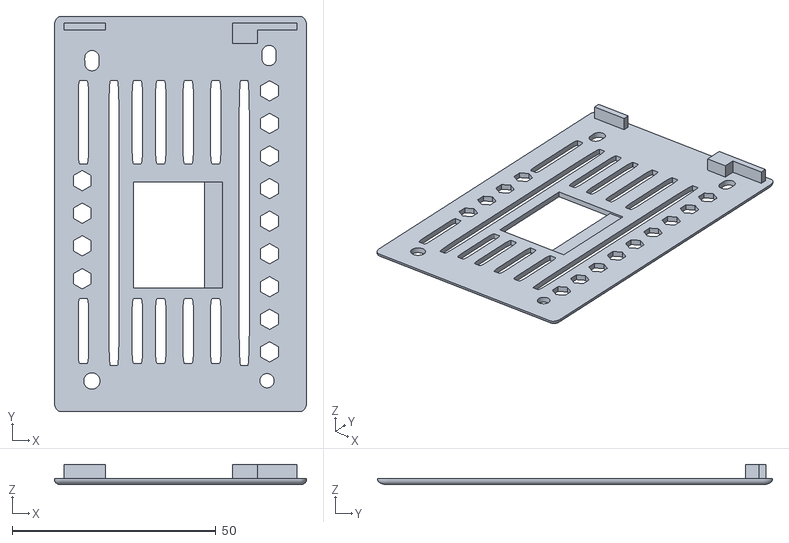
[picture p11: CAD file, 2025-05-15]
Enclosure/Mini/Mini_Enclosure_C.stl
62.0 x 97.0 x 4.99

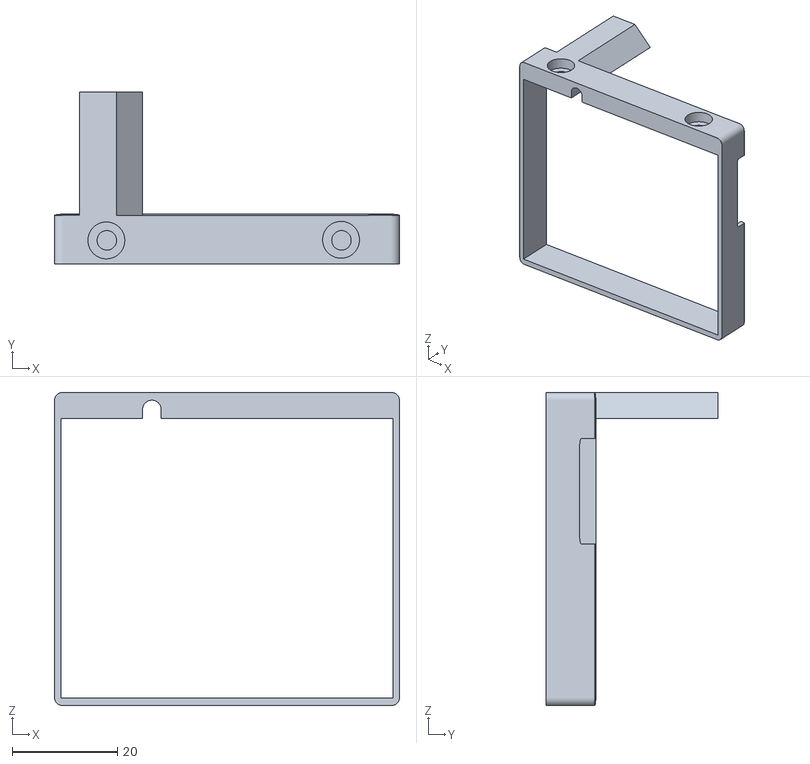
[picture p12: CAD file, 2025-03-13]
Enclosure/Enclosure_Bracket_B.stl
65.5 x 32.7 x 59.5

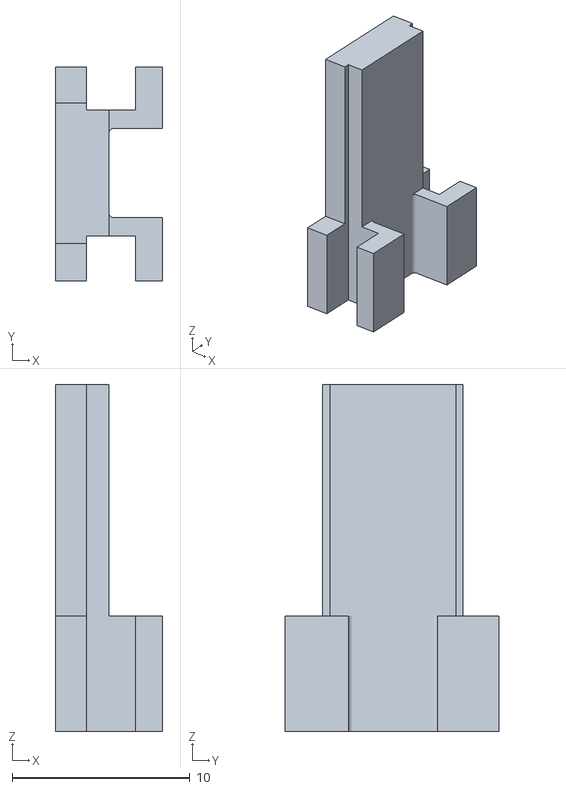
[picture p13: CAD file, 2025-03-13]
Enclosure/Mini/Enclosure_Button.stl
6.00 x 12.0 x 19.5

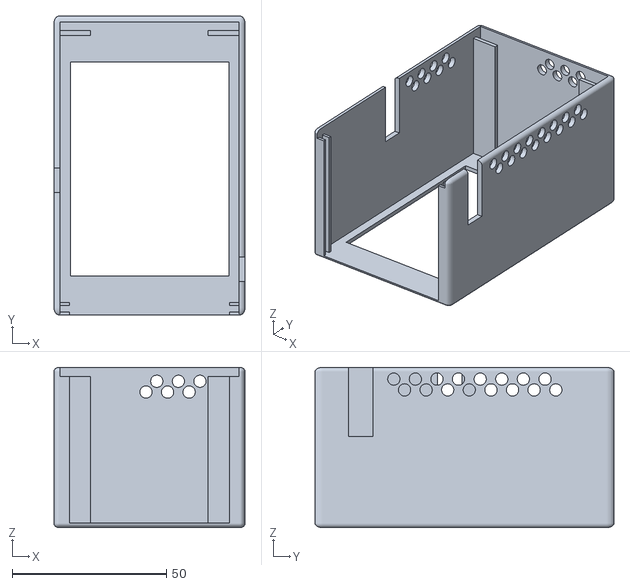
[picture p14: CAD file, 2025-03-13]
Enclosure/Enclosure_A.stl
62.0 x 97.0 x 52.0

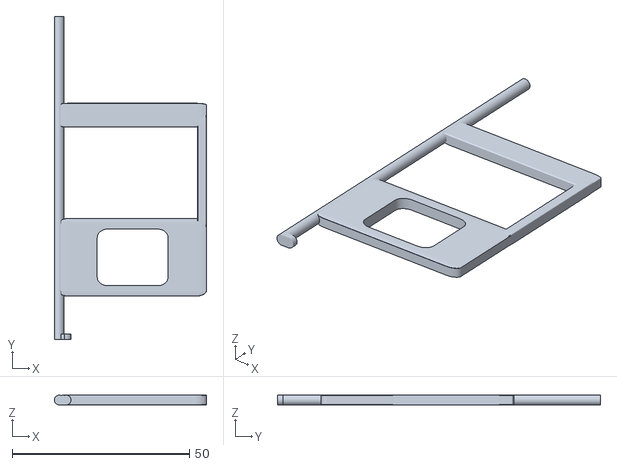
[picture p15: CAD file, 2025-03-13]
Enclosure/Enclosure_Bracket_C.stl
43.0 x 91.2 x 2.75

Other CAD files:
Enclosure/Mini/Mini_Enclosure_B.stl

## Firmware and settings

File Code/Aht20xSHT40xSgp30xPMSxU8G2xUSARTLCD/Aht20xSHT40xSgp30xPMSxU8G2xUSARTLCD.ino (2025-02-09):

#include <Wire.h>
#include <AHT20.h>
#include <Adafruit_SHT4x.h>
#include <SGP30.h>
#include <SoftwareSerial.h> 
#include <PMS.h>
#include <Arduino.h>
#include <U8g2lib.h>
#include <SPI.h>
#define imgWidth 128
#define imgHeight 64
SoftwareSerial Serial1(2, 3); // Arduino Pin2 is set to RX, Pin3 is set to TX
SoftwareSerial TJC(8,9);


PMS pms(Serial1);
PMS::DATA data;
SGP30 SGP;
Adafruit_SHT4x sht4 = Adafruit_SHT4x();
AHT20 aht20;
U8G2_SSD1306_128X64_NONAME_1_HW_I2C u8g2(U8G2_R0, /* reset=*/ U8X8_PIN_NONE); //Arduino搭配SSD1306(0.96" OLED)用這行

float TT,HH,AHT_T,AHT_H,SHT_T,SHT_H,H2,ETH;
int pm1,pm2,pm3,HT_SW,HT_adjustment_C;
unsigned short int TVOCa,ECO2a;//USART HMI
signed short int TTT,TTA,TTS,HHH,HHA,HHS,HH2,EETH;//USART HMI
unsigned short int TVOC,ECO2;
//char ;
bool HT_adjustment_A=false,HT_adjustment_B=false;

int val1,val3,val4;
float val2;


void setup()
{
  Serial.begin(9600);
  TJC.begin(9600);
  Serial1.begin(9600);
  

  pinMode( 7, INPUT_PULLUP );  //SWitch on/off
  while (!Serial){
    delay(10);
  }
  Wire.begin(); //Join I2C bus
  //Serial.println(F("Humidity AHT20 examples"));
  //Check if the AHT20 will acknowledge
  HT_line();
  

  if (! SGP.begin()){
    Serial.println(F("SGP Sensor not found :("));
    while (1);
  }
  SGP.GenericReset();
  u8g2.begin();
  u8g2.clearBuffer();
  }

void loop()
{
  //SGP.measure(true); //  returns false if no measurement is made 
  //HT_adjustment();
  if (pms.read(data))
  {
    HT_adjustment();//load debug..
    Serial.print(F("Temperature sensor abnormal code："));
    Serial.println(HT_SW);
    switch (HT_SW) {
      case 1:
      SHT40();
      TT = SHT_T; HH = SHT_H;
      break;

      case 2:
      AHT20();
      TT = AHT_T; HH = AHT_H;
      break;

      case 3:
      break;

      default:
      AHT20();
      SHT40();
      TT = (AHT_T+SHT_T)/2; HH = (AHT_H+SHT_H)/2;
      break;
      }
  
    HT_adjustment_txt();
    SGP30();
    PMS();
    HT_A();
    powerBT();
    USART_HMI();

    //HT_line();
  //delay(1000);
  

  }
}


void HT_line(void){

  HT_SW = 0;
  if (! aht20.begin())
  {
    Serial.println(F("AHT20 not detected. Please check wiring. Freezing."));
    HT_SW = HT_SW+1;
   // while (1);
    delay(100);
  }
  
  
  if (! sht4.begin()) {
    Serial.println(F("Couldn't find SHT4x"));
    HT_SW = HT_SW+2;
    //while (1) 
    delay(100);
  }
}


void AHT20(void)
{
  AHT_T = aht20.getTemperature();
  AHT_H = aht20.getHumidity();
  //If a new measurement is available
  //if (aht20.isConnected() == true)
  {
    //Get the new temperature and humidity value
    //float temperature = aht20.getTemperature();
    //float humidity = aht20.getHumidity();
    //Print the results
    Serial.print(F("AHT_Temperature: "));
    Serial.print(AHT_T, 2);
    Serial.print(F(" C\t"));
    Serial.print(F("Humidity: "));
    Serial.print(AHT_H, 2);
    Serial.print(F("% RH"));
    Serial.println();
  }
}

void SHT40(void){
  sensors_event_t humidity, temp;
  sht4.getEvent(&humidity, &temp);// populate temp and humidity objects with fresh data
  SHT_T=temp.temperature; 
  SHT_H=humidity.relative_humidity;
  Serial.print(F("SHT_Temperature: ")); Serial.print(temp.temperature); Serial.println(F(" degrees C"));
  Serial.print(F("SHT_Humidity: ")); Serial.print(humidity.relative_humidity); Serial.println(F("% rH"));
  /*Serial.print("Read duration (ms): ");
  Serial.println(timestamp);*/
}

void SGP30(void){
  SGP.measure(true);      //  returns false if no measurement is made 
  TVOC=SGP.getTVOC();   ECO2=SGP.getCO2();    H2=SGP.getH2();   ETH=SGP.getEthanol();
  if(SGP.getH2_raw() > 13119){ //0.5 the following situations is not appropriate 以下不適配
    H2=0; 
  }
  if(SGP.getEthanol_raw() > 18471){ //0.5the following situations is not appropriate 以下不適配
    ETH=0;
  }

  Serial.print(F("TVOC (ppb): "));
  Serial.print(TVOC);
  Serial.print(F("\t eCO2 (ppm): "));
  Serial.println(ECO2);
  Serial.print(F("H2 (ppm): "));
  Serial.print(H2);
  Serial.print(F("\t ETH (ppm):"));
  Serial.println(ETH);
  //Serial.println();
}

void PMS(void){
  pm1=data.PM_AE_UG_1_0;
  pm2=data.PM_AE_UG_2_5;
  pm3=data.PM_AE_UG_10_0;
  Serial.print(F("PM 1.0 (ug/m3): "));
  Serial.println(pm1);
  Serial.print(F("PM 2.5 (ug/m3): "));
  Serial.println(pm2);
  Serial.print(F("PM 10.0 (ug/m3): "));
  Serial.println(pm3);
  Serial.println();
}

void HT_A(void){
  //u8g2.setFont(u8g2_font_UnnamedDOSFontIV_tr); //Set font 設定字型
  u8g2.firstPage();
  do {
    u8g2.setDrawColor(1);
    u8g2.setFont(u8g2_font_streamline_weather_t);//Set font 設定字型
    u8g2.drawGlyph(
      5, 23, 0x36);

    u8g2.setDrawColor(0);
    switch (HT_SW) {
      case 1:
      u8g2.drawBox(18,4,5,6); //1
      break;

      case 2:
      u8g2.drawBox(18,4,5,10);
      u8g2.setDrawColor(1);
      u8g2.drawBox(18,8,4,2);
      break;

      case 3:
      u8g2.drawBox(18,4,5,10);
      break;

      default:
      u8g2.drawBox(18,4,5,3); //2
      break;
      }
    //u8g2.drawBox(18,4,5,3); //2
    //u8g2.drawBox(18,4,5,6); //1
    //u8g2.drawBox(18,4,5,10); //0
    //u8g2.setDrawColor(1);
    //u8g2.drawBox(18,8,4,2); //

    u8g2.setDrawColor(1);
    u8g2.setFont(u8g2_font_luBIS18_tr);//Set font 設定字型
    u8g2.setCursor(26,19);
    u8g2.print(":");
    u8g2.print(TT,1);
    u8g2.print("*C");

    u8g2.setFont(u8g2_font_open_iconic_thing_2x_t); //Set font 設定字型
    u8g2.drawGlyph(5, 40, 0x48);
    u8g2.setFont(u8g2_font_luBIS18_tr);//Set font 設定字型
    u8g2.setCursor(26,40);
    u8g2.print(":");
    u8g2.print(HH,1);
    u8g2.print(" %");


    u8g2.setFont(u8g2_font_squeezed_b6_tr); //Set font 設定字型
    u8g2.setCursor(0,48);
    u8g2.print("TVOC : ");
    u8g2.print(TVOC);
    u8g2.setCursor(70,48);
    u8g2.print("ppb");
    if (HT_adjustment_A == true){
      u8g2.setCursor(122,51);
      u8g2.print("*");
    }
    
    u8g2.setCursor(0,56);
    u8g2.print("eCO2 : ");
    u8g2.print(ECO2);
    u8g2.setCursor(70,56);
    u8g2.print("ppm");

    u8g2.setCursor(0,64);
    u8g2.print("PM2.5: ");
    u8g2.print(pm2);
    //u8g2.setCursor(70,64);

    
    u8g2.setCursor(70,64);
    u8g2.print("BAT: ");
    //u8g2.print(val2);
    val3=(val2-3)*93;
    if(val3<0){
      val3=0;
    }
    else if(val3>=100)
    {
      val3=100;
    }

    u8g2.print(val3);
    u8g2.print(" %");

  } while ( u8g2.nextPage() );
}

void HT_adjustment(void){
  if (digitalRead( 7 ) == false){
    HT_adjustment_C=HT_adjustment_C+1;
    if (HT_adjustment_C >3){
    if (HT_adjustment_A ==true){
      SGP.GenericReset();
      HT_adjustment_A =false;
      HT_adjustment_C=0;
      //Serial.print(F("HT adjustment off !!!"));
    }
  else if(HT_adjustment_A ==false){
    SGP.GenericReset();
    HT_adjustment_A =true;
    HT_adjustment_C=0;
  }}}
  else{HT_adjustment_C=0;}
  
}


void HT_adjustment_txt(void){
  if (HT_adjustment_A == true)
  {
    //Serial.println(HT_adjustment_A);
    //HT_adjustment_A ==true;
    Serial.print(F("HT adjustment on :"));
    Serial.println(SGP.setRelHumidity(TT, HH), HEX);
  }
  else
  {
    //Serial.println(HT_adjustment_A);
    Serial.println(F("HT adjustment off !!!"));

  } }

void USART_HMI(void){

  TTT=TT*100;
  char strTT[20];
  sprintf(strTT, "TempT.val=%d", TTT);
  TJC.print(strTT);
  //TJC.write("TempT.val=%d", TTT);
  TJC.write(0xff);
  TJC.write(0xff);
  TJC.write(0xff);

  TTA=AHT_T*100;
  char strTTA[20];
  sprintf(strTTA, "TempA.val=%d", TTA);
  TJC.print(strTTA);
  //TJC.write("TempT.val=%d", TTT);
  TJC.write(0xff);
  TJC.write(0xff);
  TJC.write(0xff);

  TTS=SHT_T*100;
  char strTTS[20];
  sprintf(strTTS, "TempS.val=%d", TTS);
  TJC.print(strTTS);
  //TJC.write("TempT.val=%d", TTT);
  TJC.write(0xff);
  TJC.write(0xff);
  TJC.write(0xff);


  HHH=HH*100;
  char strHH[20];
  sprintf(strHH, "HumiT.val=%d", HHH);
  TJC.print(strHH);
  TJC.write(0xff);
  TJC.write(0xff);
  TJC.write(0xff);

  HHA=AHT_H*100;
  char strHHA[20];
  sprintf(strHHA, "HumiA.val=%d", HHA);
  TJC.print(strHHA);
  TJC.write(0xff);
  TJC.write(0xff);
  TJC.write(0xff);

  HHS=SHT_H*100;
  char strHHS[20];
  sprintf(strHHS, "HumiS.val=%d", HHS);
  TJC.print(strHHS);
  TJC.write(0xff);
  TJC.write(0xff);
  TJC.write(0xff);


  TVOCa=TVOC;
  if (TVOCa>=30000){
    TVOCa=30000;
  }
  char strTVOC[20];
  sprintf(strTVOC, "TVOC.val=%d", TVOCa);
  TJC.print(strTVOC);
  TJC.write(0xff);
  TJC.write(0xff);
  TJC.write(0xff);

  ECO2a=ECO2;
  if (ECO2a>=30000){
    ECO2a=30000;
  }
  char strECO2[20];
  sprintf(strECO2, "CO2.val=%d",ECO2a);
  //sprintf(strECO2, "n2.val=%d", ECO2);
  TJC.print(strECO2);
  TJC.write(0xff);
  TJC.write(0xff);
  TJC.write(0xff);

  HH2=H2*10;
  char strH2[20];
  sprintf(strH2, "H2.val=%d", HH2);
  TJC.print(strH2);
  TJC.write(0xff);
  TJC.write(0xff);
  TJC.write(0xff);

  EETH=ETH*10;
  char strETH[20];
  sprintf(strETH, "ETH.val=%d", EETH);
  TJC.print(strETH);
  TJC.write(0xff);
  TJC.write(0xff);
  TJC.write(0xff);


  char strpm2[20];
  sprintf(strpm2, "PM25.val=%d", pm2);
  TJC.print(strpm2);
  TJC.write(0xff);
  TJC.write(0xff);
  TJC.write(0xff);

  char strpm1[20];
  sprintf(strpm1, "PM10.val=%d", pm1);
  TJC.print(strpm1);
  TJC.write(0xff);
  TJC.write(0xff);
  TJC.write(0xff);

  char strpm3[20];
  sprintf(strpm3, "PM100.val=%d", pm3);
  TJC.print(strpm3);
  TJC.write(0xff);
  TJC.write(0xff);
  TJC.write(0xff);

  char strBAT[20];
  val4=val1/2.8;
  sprintf(strBAT, "BAT.val=%d", val4);
  TJC.print(strBAT);
  TJC.write(0xff);
  TJC.write(0xff);
  TJC.write(0xff);

  char strHTADJ[20];
  sprintf(strHTADJ, "HTADJ.val=%d", HT_adjustment_A);
  TJC.print(strHTADJ);
  TJC.write(0xff);
  TJC.write(0xff);
  TJC.write(0xff);
}


void powerBT(void)
{
float temp;
      val1=analogRead(A0);
      temp=val1/2.8;
      val2=(temp/10);

      Serial.print(F("Voltage value："));
      Serial.print(val1);
      Serial.print(F("    "));
      Serial.println(val2);
      /*Serial.print(F("    "));
      Serial.println(val3);
      Serial.println(HT_adjustment_A);
      Serial.println(HT_adjustment_B);
      Serial.println(HT_adjustment_C);*/
}

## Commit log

2025-02-09 Arduino code
2025-04-22 Update README_US.md
    en ‼️
2025-05-20 Create Gerber_PCB_Air-Quality-Monitor_2025-05-21.zip
    Gerber_PCB
